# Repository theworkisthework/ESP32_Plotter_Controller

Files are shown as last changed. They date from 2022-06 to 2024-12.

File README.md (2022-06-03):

# ESP32 Plotter Controller PCB
 
Released under an MIT licence, no warranty implied or given, use at own risk etc etc.

This is a two axis stepper controller based on the ESP32 and TMC2130 stepper drivers. It is intended to be used with drawing machines and plotters.

Firmware https://github.com/theworkisthework/Grbl_Esp32 (This is a Fork of Grbl_Esp32, if its out of date, you probably only need the config file from this fork). Tested with standard and corexy kinematics and a solenoid/relay for the spindle.

Revision B (aka 'Emerald Dingo') embeds an ESP32 module on the board along with comms and USB C connector. The peripheral connectors are all JST PH2.0 connectors. Also added E-Stop connector (J18).

[Schematic]( https://github.com/theworkisthework/ESP32_Plotter_Controller/blob/main/ESP32_Plotter_Controller_Schematic_RevB1.pdf )

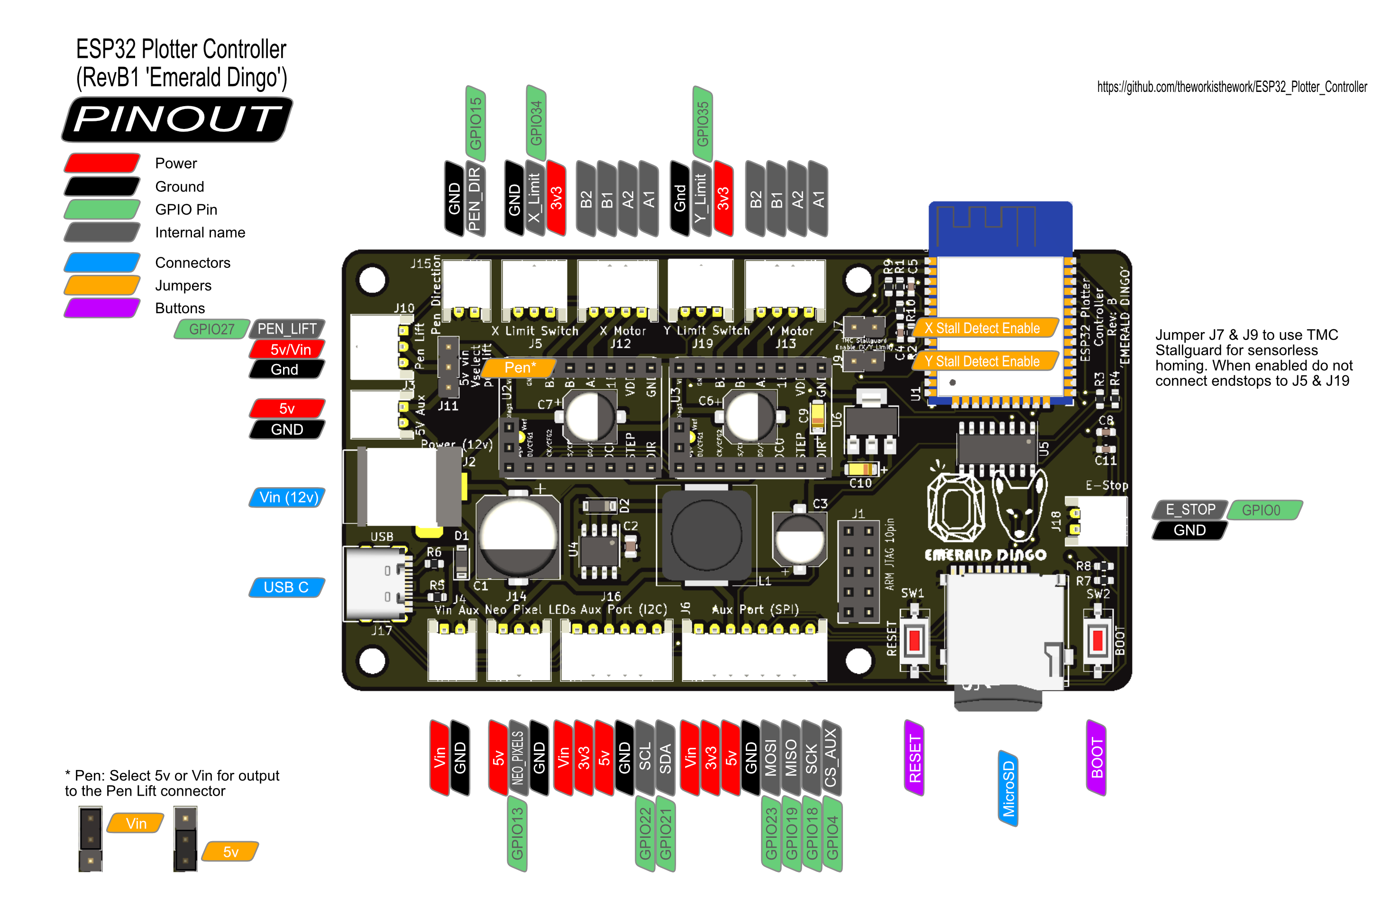
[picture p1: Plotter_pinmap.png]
Pinmap


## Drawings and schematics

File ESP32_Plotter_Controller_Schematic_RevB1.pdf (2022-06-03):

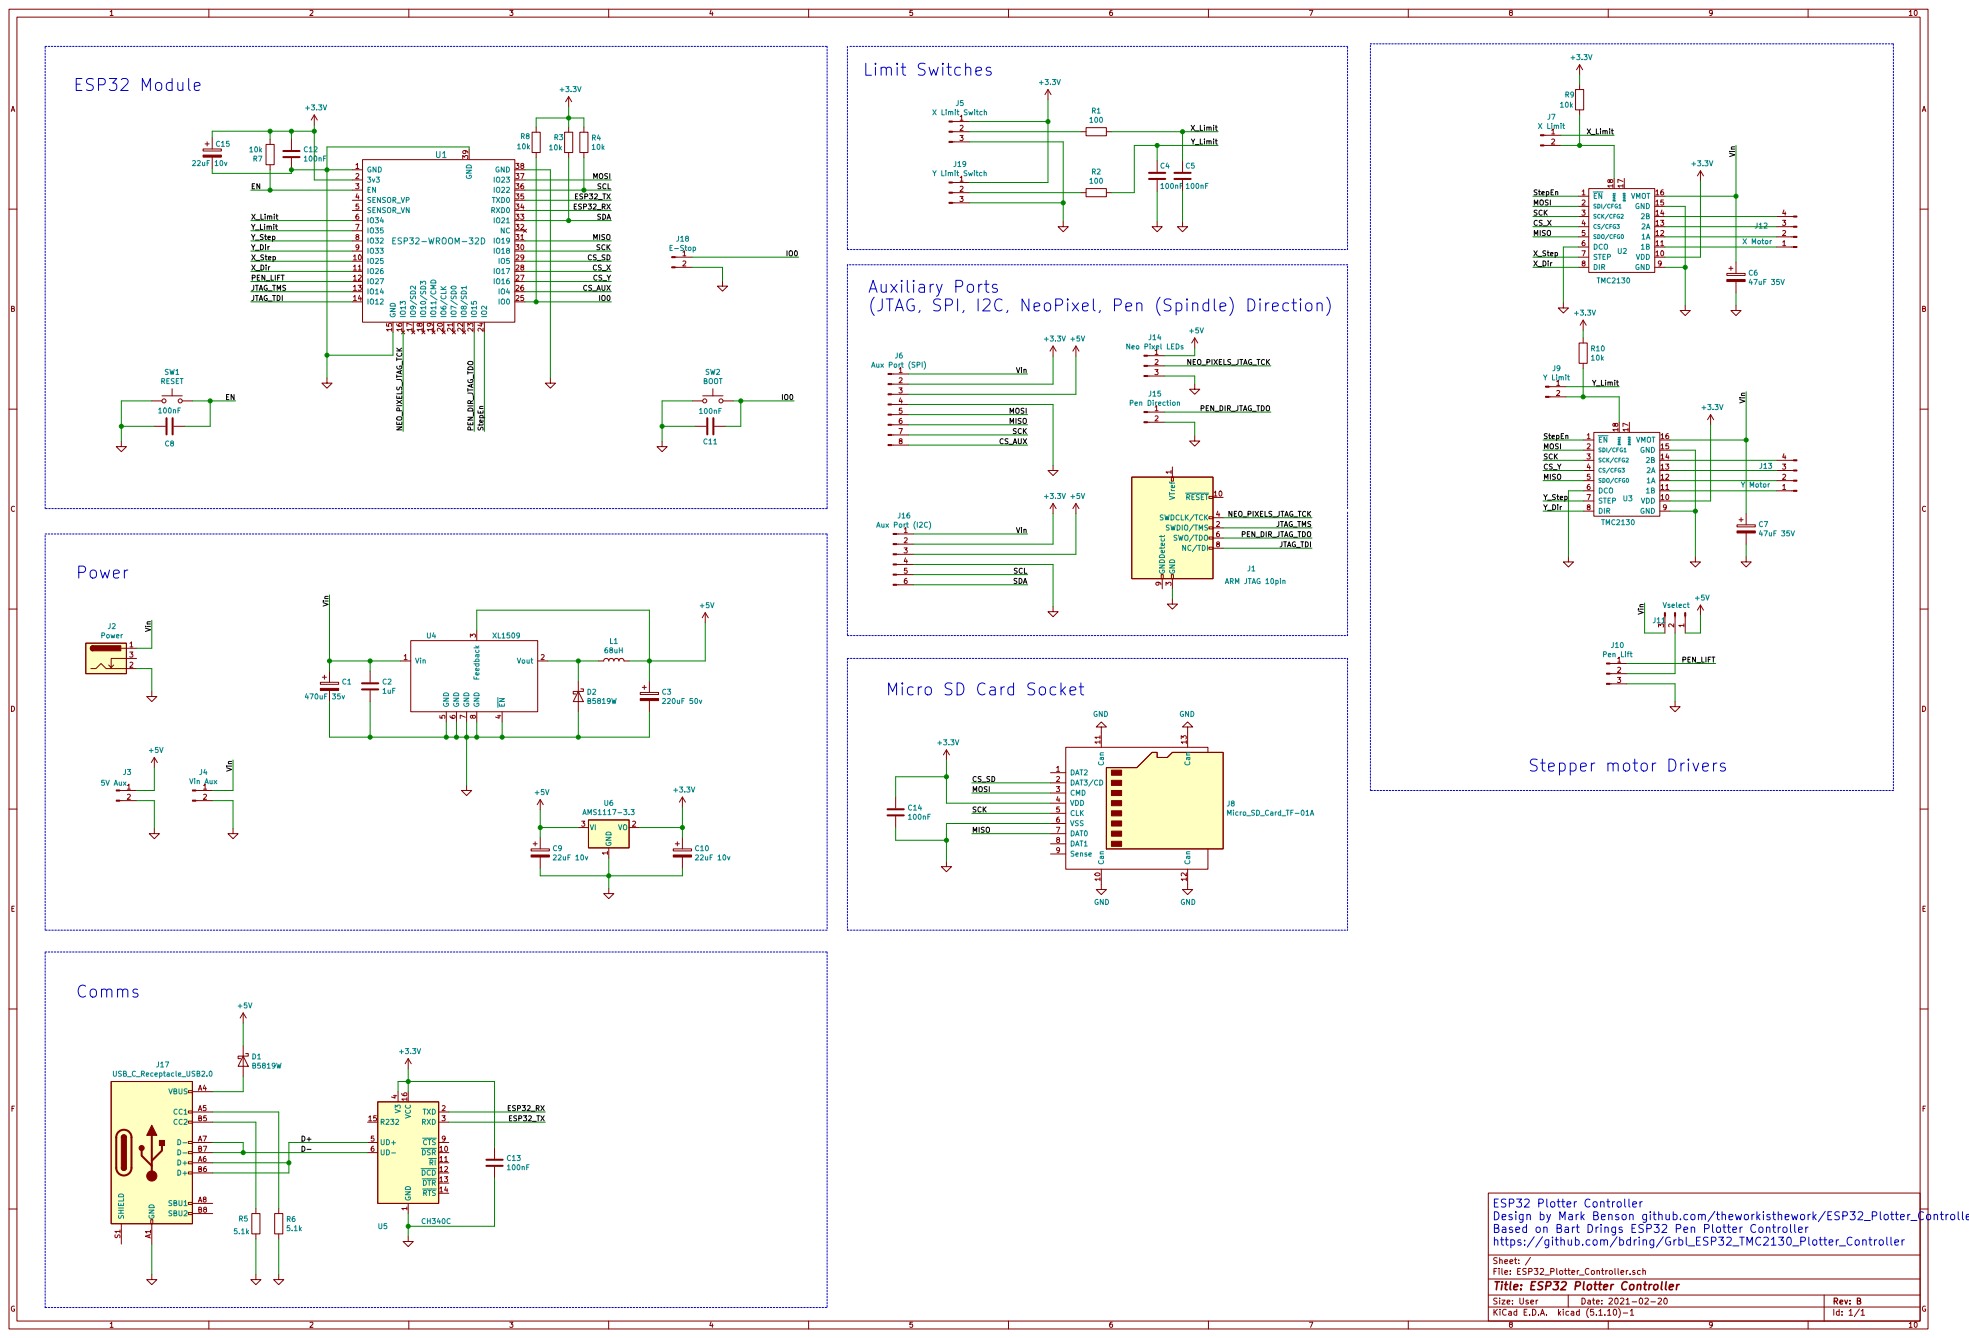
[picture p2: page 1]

Auxiliary Ports
(JTAG, SPI, I2C, NeoPixel, Pen (Spindle) Direction)

SDA MISO MOSI SCK CS_SD

3 SWDCLK/TCK 4 SWO/TDO 6 NC/TDI 8 GNDDetect 9

Micro SD Card Socket

1 DSR 10 RI 11 DCD 12 DTR 13 RTS 14 R232 15 VCC 16 TXD 2 RXD 3 V3

ESP32 Plotter Controller
Design by Mark Benson github.com/theworkisthework/ESP32_Plotter_Controller
Based on Bart Drings ESP32 Pen Plotter Controller
https://github.com/bdring/Grbl_ESP32_TMC2130_Plotter_Controller

File: ESP32_Plotter_Controller.sch Sheet: /
Id: 1/1 Title: ESP32 Plotter Controller

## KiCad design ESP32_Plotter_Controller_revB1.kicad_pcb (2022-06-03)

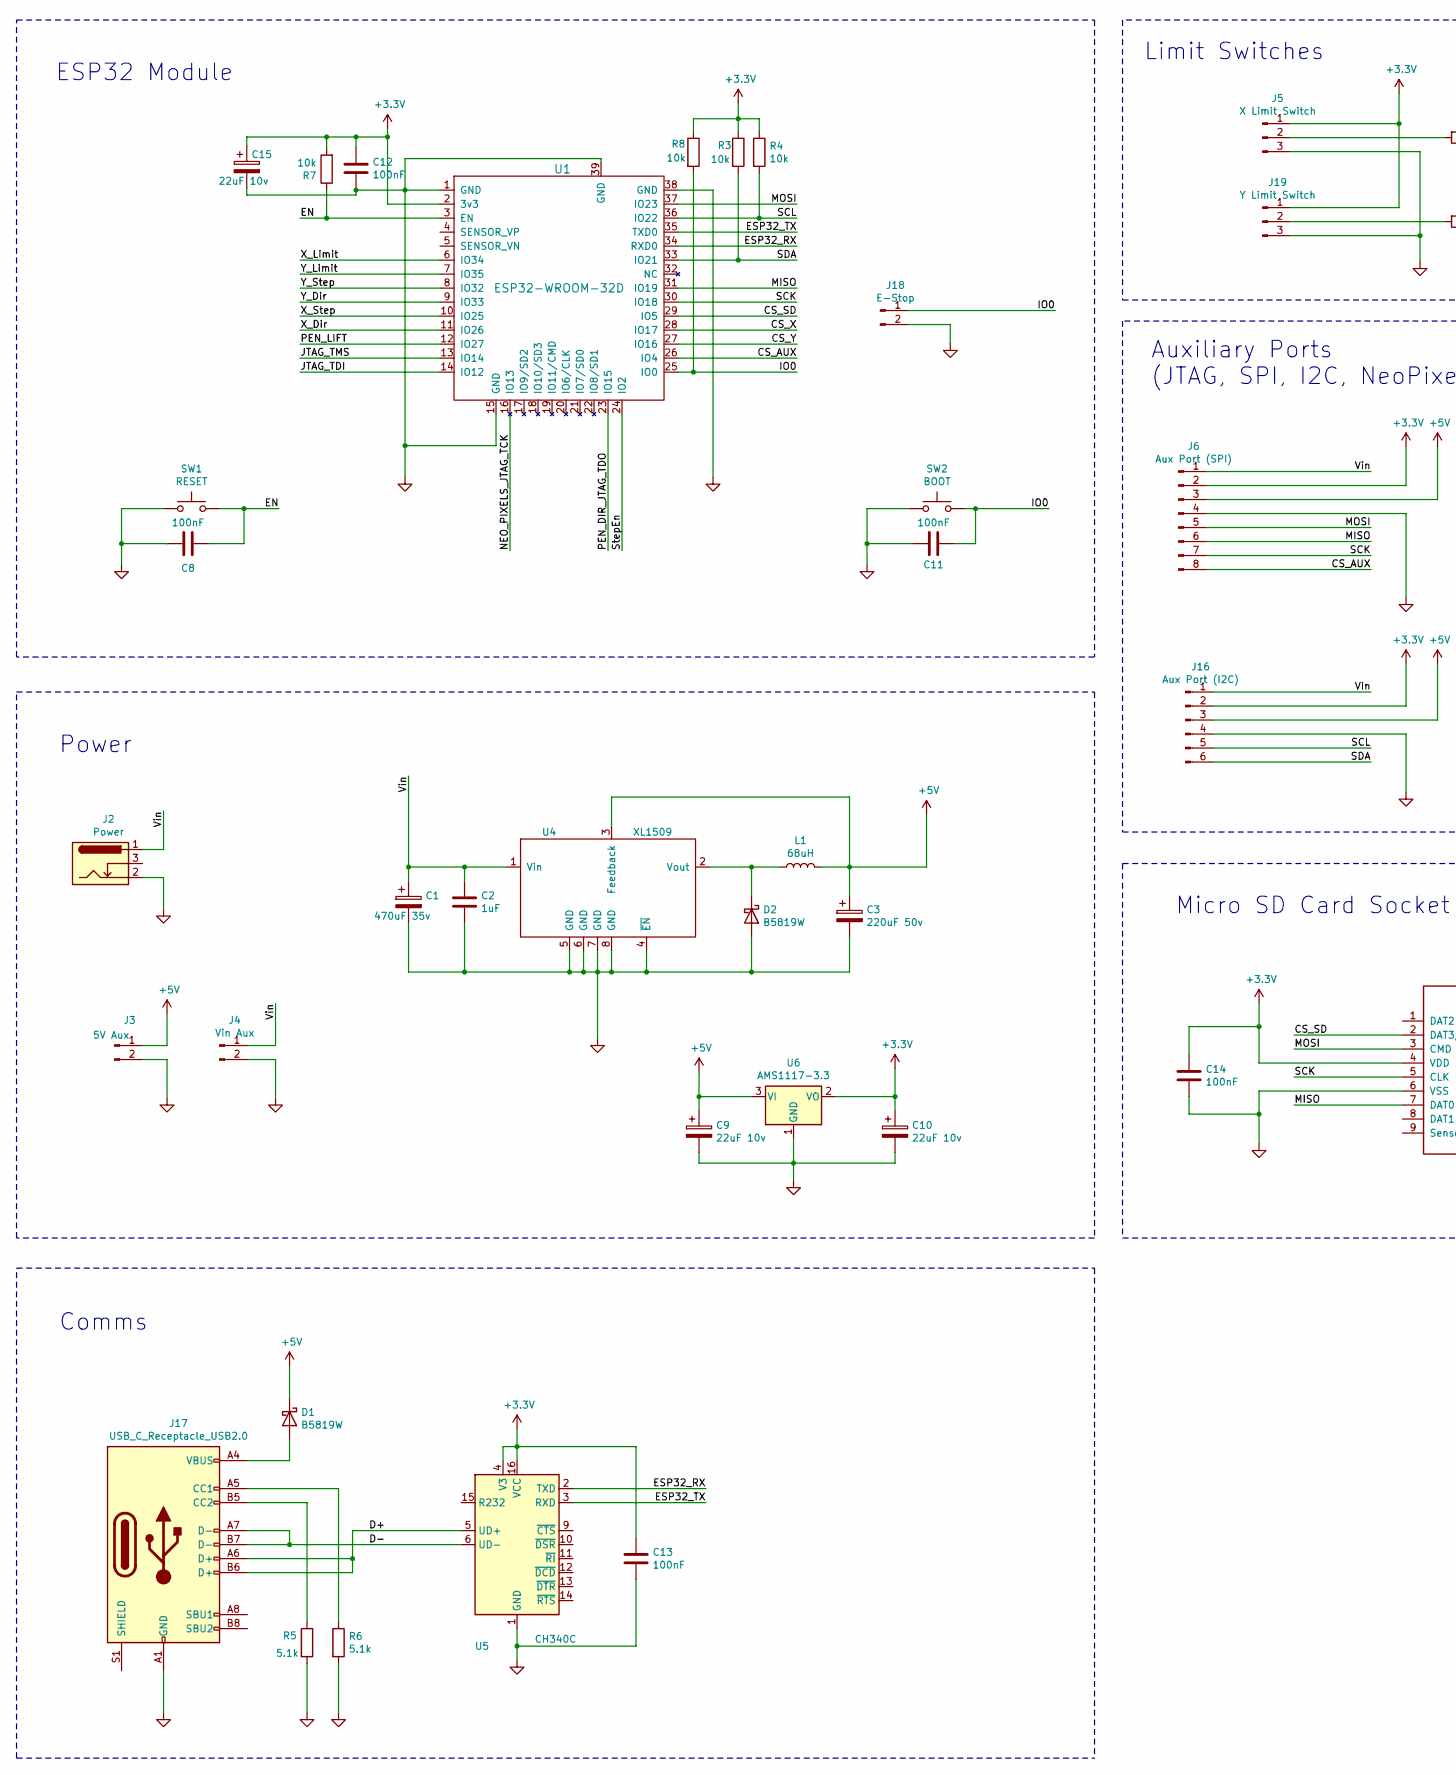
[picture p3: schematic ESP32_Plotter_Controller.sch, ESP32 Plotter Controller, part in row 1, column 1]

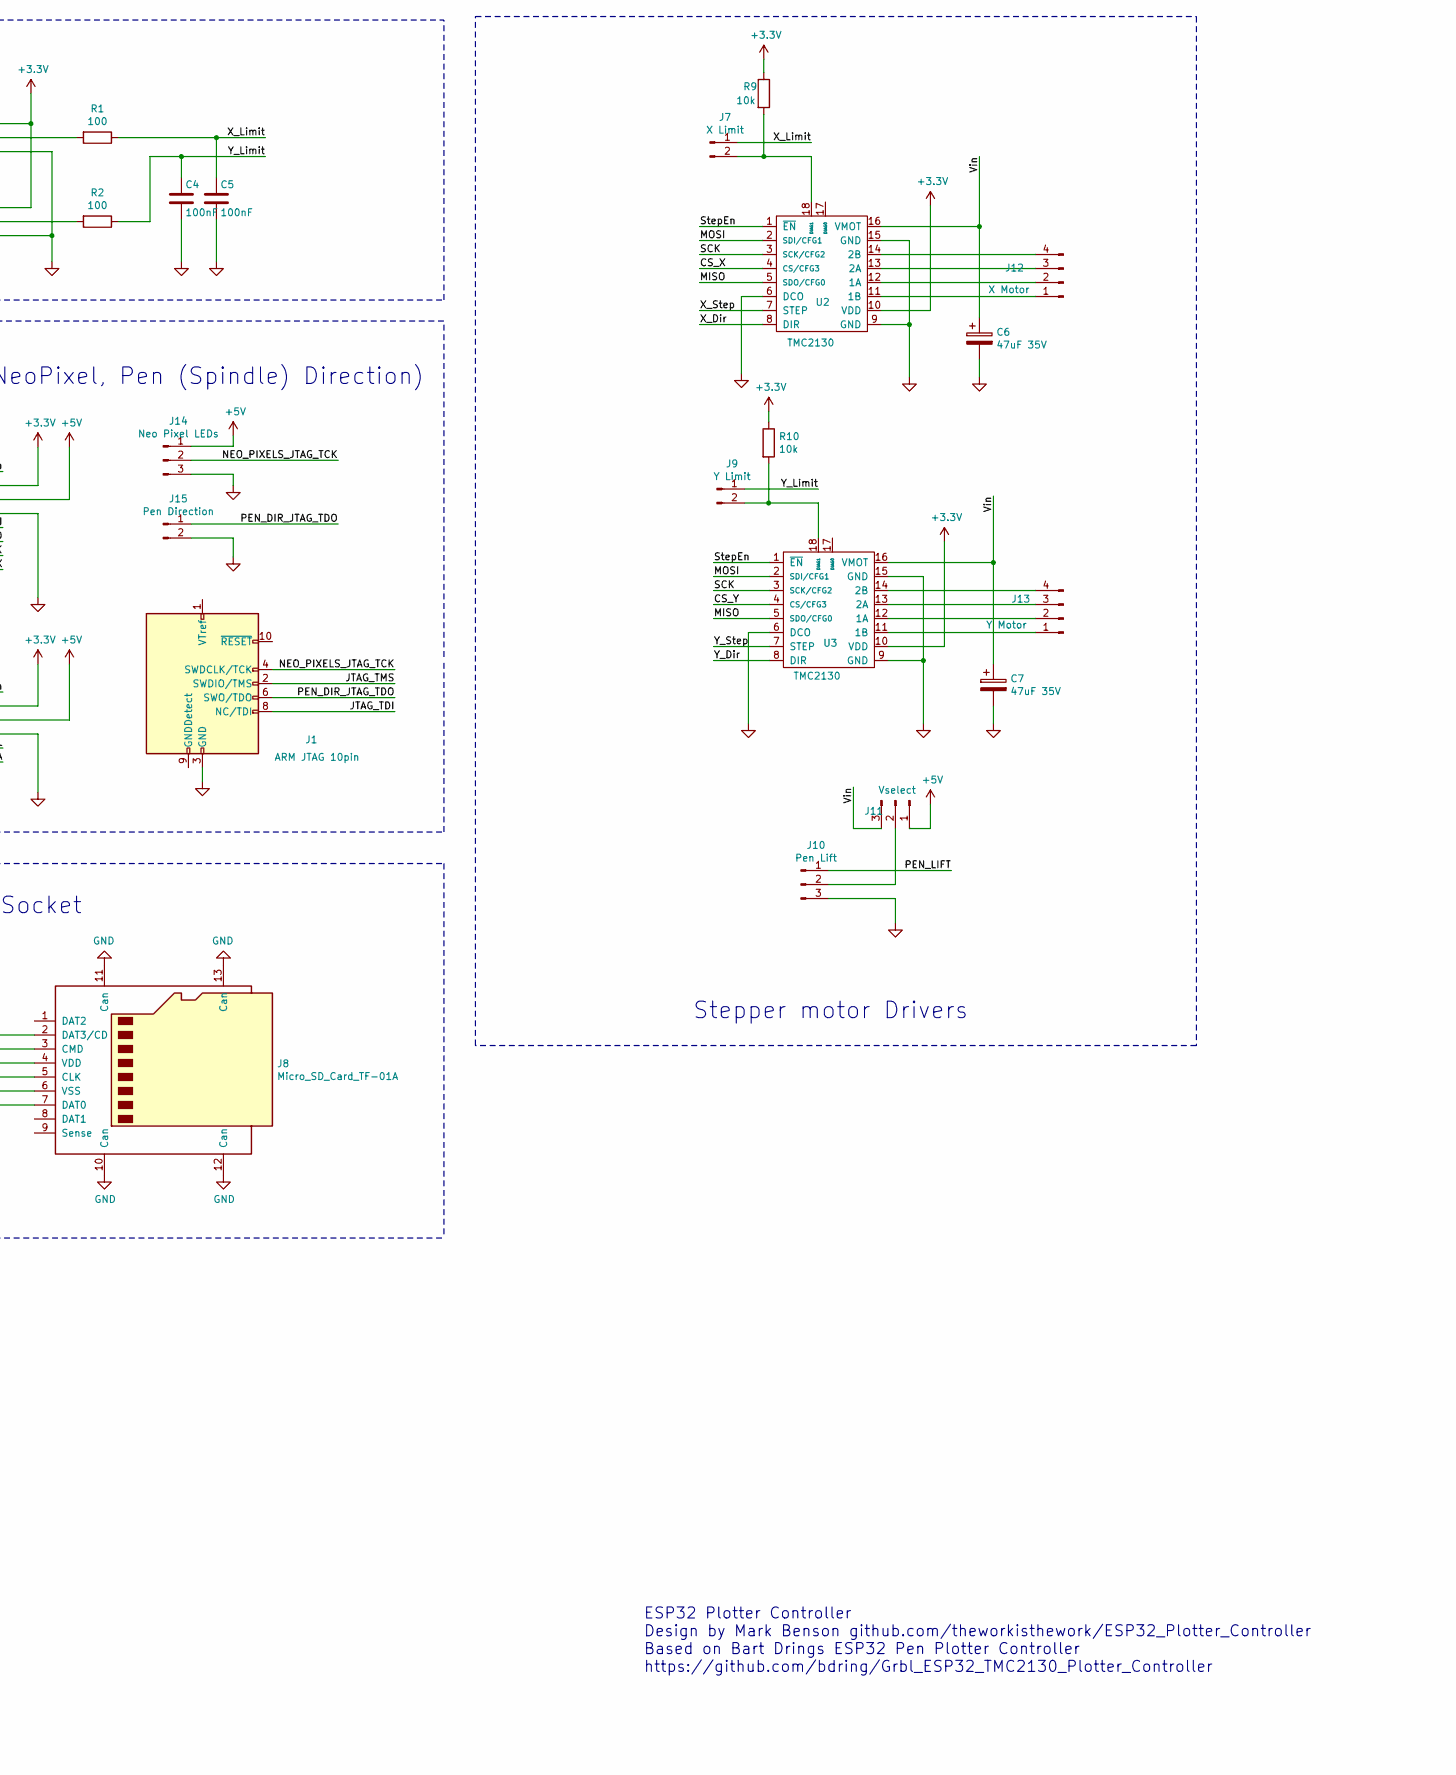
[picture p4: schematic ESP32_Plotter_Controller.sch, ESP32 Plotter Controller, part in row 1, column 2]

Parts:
C1: 470uF 35v; CP_Elec_10x10; LCSC C280412
C2: 1uF; C_0805_2012Metric; LCSC C28323
C3: 220uF 50v; CP_Elec_10x10; LCSC alt2 C242139
C4, C5, C8, C11, C12, C13, C14: 100nF; C_0603_1608Metric; LCSC C42998
C6, C7: 47uF 35V; CP_Elec_6.3x5.7; LCSC C176688
C9, C10, C15: 22uF 10v; CP_EIA-3216-18_Kemet-A; LCSC C118989
D1, D2: B5819W; D_SOD-123; LCSC C8598
J1: ARM JTAG 10pin; PinSocket_2x05_P2.54mm_Vertical; LCSC C92270
J2: Power; BarrelJack_Horizontal; LCSC C130239
J3: 5V Aux; JST_PH_S2B-PH-K_1x02_P2.00mm_Horizontal; LCSC C16965
J4: Vin Aux; JST_PH_S2B-PH-K_1x02_P2.00mm_Horizontal; LCSC C16965
J5: X Limit Switch; JST_PH_S3B-PH-K_1x03_P2.00mm_Horizontal; LCSC C10400
J6: Aux Port (SPI); JST_PH_S8B-PH-K_1x08_P2.00mm_Horizontal; LCSC C14531
J7: X Limit; PinHeader_1x02_P2.54mm_Vertical; LCSC C160332
J8: Micro_SD_Card_TF-01A; HK-TF01A; LCSC C91145
J9: Y Limit; PinHeader_1x02_P2.54mm_Vertical; LCSC C160332
J10: Pen Lift; JST_PH_S3B-PH-K_1x03_P2.00mm_Horizontal; LCSC C10400
J11: Vselect; PinHeader_1x03_P2.54mm_Vertical; LCSC C49257
J12: X Motor; JST_PH_S4B-PH-K_1x04_P2.00mm_Horizontal; LCSC C10401
J13: Y Motor; JST_PH_S4B-PH-K_1x04_P2.00mm_Horizontal; LCSC C10401
J14: Neo Pixel LEDs; JST_PH_S3B-PH-K_1x03_P2.00mm_Horizontal; LCSC C10400
J15: Pen Direction; JST_PH_S2B-PH-K_1x02_P2.00mm_Horizontal; LCSC C16965
J16: Aux Port (I2C); JST_PH_S6B-PH-K_1x06_P2.00mm_Horizontal; LCSC C5662
J17: USB_C_Receptacle_USB2.0; USB_C_Receptacle_HRO_TYPE-C-31-M-12; LCSC C165948
J18: E-Stop; JST_PH_S2B-PH-K_1x02_P2.00mm_Horizontal; LCSC C16965
J19: Y Limit Switch; JST_PH_S3B-PH-K_1x03_P2.00mm_Horizontal; LCSC C10400
L1: 68uH; L_12x12mm_H6mm; LCSC C439406
R1, R2: 100; R_0603_1608Metric; LCSC C25201
R3, R4, R7, R8, R9, R10: 10k; R_0603_1608Metric; LCSC C98220
R5, R6: 5.1k; R_0603_1608Metric; LCSC C269716
SW1: RESET; K2-1107ST; LCSC C118141
SW2: BOOT; K2-1107ST; LCSC C118141
U1: ESP32-WROOM-32D; ESP32-WROOM-32; LCSC C82899
U2, U3: TMC2130; StepstickTMCv2; LCSC C27438
U4: XL1509; SO-8_3.9x4.9mm_P1.27mm; LCSC C61063
U5: CH340C; SOIC-16_3.9x9.9mm_P1.27mm; LCSC C84681
U6: AMS1117-3.3; SOT-223-3_TabPin2; LCSC C351784

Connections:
+3V3: C10.1, C12.1, C13.1, C14.1, C15.1, J5.1, J6.2, J8.4 (VDD), J16.2, J19.1, R3.1, R4.1, R7.2, R8.1, R9.1, R10.1, U1.2 (3v3), U2.10 (VDD), U3.10 (VDD), U5.4 (V3), U5.16 (VCC), U6.2 (VO)
+5V: C3.1, C9.1, D1.1 (K), J3.1, J6.3, J11.1, J14.1, J16.3, L1.2, U4.3 (Feedback), U6.3 (VI)
/CS_AUX: J6.8, U1.26 (IO4)
/CS_SD: J8.2 (DAT3/CD), U1.29 (IO5)
/CS_X: U1.28 (IO17), U2.4 (CS/CFG3)
/CS_Y: U1.27 (IO16), U3.4 (CS/CFG3)
/D+: J17.A6 (D+), J17.B6 (D+), U5.5 (UD+)
/D-: J17.A7 (D-), J17.B7 (D-), U5.6 (UD-)
/EN: C8.2, R7.1, SW1.2, U1.3 (EN)
/ESP32_RX: U1.34 (RXD0), U5.2 (TXD)
/ESP32_TX: U1.35 (TXD0), U5.3 (RXD)
/IO0: C11.1, J18.1, R8.2, SW2.2, U1.25 (IO0)
/JTAG_TDI: J1.8 (NC/TDI), U1.14 (IO12)
/JTAG_TMS: J1.2 (SWDIO/TMS), U1.13 (IO14)
/MISO: J6.6, J8.7 (DAT0), U1.31 (IO19), U2.5 (SDO/CFG0), U3.5 (SDO/CFG0)
/MOSI: J6.5, J8.3 (CMD), U1.37 (IO23), U2.2 (SDI/CFG1), U3.2 (SDI/CFG1)
/NEO_PIXELS_JTAG_TCK: J1.4 (SWDCLK/TCK), J14.2, U1.16 (IO13)
/PEN_DIR_JTAG_TDO: J1.6 (SWO/TDO), J15.1, U1.23 (IO15)
/PEN_LIFT: J10.1, U1.12 (IO27)
/SCK: J6.7, J8.5 (CLK), U1.30 (IO18), U2.3 (SCK/CFG2), U3.3 (SCK/CFG2)
/SCL: J16.5, R4.2, U1.36 (IO22)
/SDA: J16.6, R3.2, U1.33 (IO21)
/StepEn: U1.24 (IO2), U2.1 (~EN), U3.1 (~EN)
/Vin: C1.1, C2.1, C6.1, C7.1, J2.1, J4.1, J6.1, J11.3, J16.1, U2.16 (VMOT), U3.16 (VMOT), U4.1 (Vin)
/X_Dir: U1.11 (IO26), U2.8 (DIR)
/X_Limit: C5.1, J7.1, R1.1, U1.6 (IO34)
/X_Step: U1.10 (IO25), U2.7 (STEP)
/Y_Dir: U1.9 (IO33), U3.8 (DIR)
/Y_Limit: C4.1, J9.1, R2.1, U1.7 (IO35)
/Y_Step: U1.8 (IO32), U3.7 (STEP)
GND: C1.2, C2.2, C3.2, C4.2, C5.2, C6.2, C7.2, C8.1, C9.2, C10.2, C11.2, C12.2, C13.2, C14.2, C15.2, D2.2 (A), J1.3 (GND), J1.5 (GND), J2.2, J3.2, J4.2, J5.3, J6.4, J8.6 (VSS), J8.10 (Can), J8.11 (Can), J8.12 (Can), J8.13 (Can), J10.3, J14.3, J15.2, J16.4, J17.A1 (GND), J17.A12 (GND), J17.B1 (GND), J17.B12 (GND), J18.2, J19.3, R5.2, R6.2, SW1.1, SW2.1, U1.1 (GND), U1.15 (GND), U1.38 (GND), U1.39 (GND), U2.6 (DCO), U2.9 (GND), U2.15 (GND), U3.6 (DCO), U3.9 (GND), U3.15 (GND), U4.4 (~EN), U4.5 (GND), U4.6 (GND), U4.7 (GND), U4.8 (GND), U5.1 (GND), U6.1 (GND)
unnamed: D1.2 (A), J17.A4 (VBUS), J17.A9 (VBUS), J17.B4 (VBUS), J17.B9 (VBUS)
unnamed: D2.1 (K), L1.1, U4.2 (Vout)
unnamed: J5.2, R1.2
unnamed: J7.2, R9.2, U2.18 (DIAG1)
unnamed: J9.2, R10.2, U3.18 (DIAG1)
unnamed: J10.2, J11.2
unnamed: J12.1, U2.11 (1B)
unnamed: J12.2, U2.12 (1A)
unnamed: J12.3, U2.13 (2A)
unnamed: J12.4, U2.14 (2B)
unnamed: J13.1, U3.11 (1B)
unnamed: J13.2, U3.12 (1A)
unnamed: J13.3, U3.13 (2A)
unnamed: J13.4, U3.14 (2B)
unnamed: J17.A5 (CC1), R6.1
unnamed: J17.B5 (CC2), R5.1
unnamed: J19.2, R2.2

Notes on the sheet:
Micro SD Card Socket
Limit Switches
Stepper motor Drivers
ESP32 Module
Power
ESP32 Plotter Controller Design by Mark Benson github.com/theworkisthework/ESP32_Plotter_Controller Based on Bart Drings ESP32 Pen Plotter Controller https://github.com/bdring/Grbl_ESP32_TMC2130_Plotter_Controller
Auxiliary Ports (JTAG, SPI, I2C, NeoPixel, Pen (Spindle) Direction)
Comms

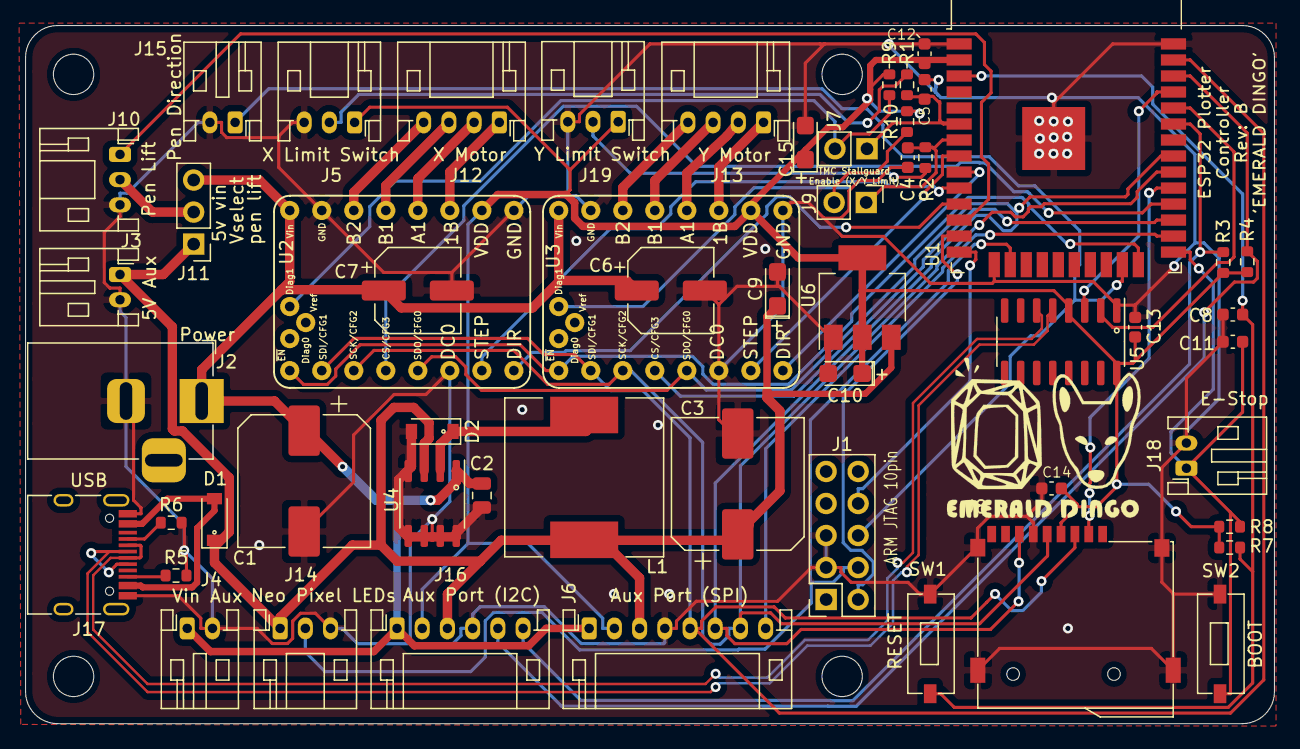
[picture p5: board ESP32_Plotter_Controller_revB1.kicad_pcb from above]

Board: 2 copper layers, 99.1 x 55.4 mm, 61 parts (1 on the bottom side), 48 nets.

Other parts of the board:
G1: LOGO; emerald_dingo_400
G2: LOGO; emerald_dingo_150
H1, H2, H3, H4: MountingHole_3.2mm_M3

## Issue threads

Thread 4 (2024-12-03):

Pin map Y Limit Switch labels incorrect

MarkJB, 2024-12-03:
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

Swap PWR & GND on J19

Closed 2024-12-07.

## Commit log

2022-06-03 Update repo links
    [ESP32_Plotter_Controller.sch, ESP32_Plotter_Controller_revB1.kicad_pcb]
2022-06-03 Update gerber files
    [ESP32_Plotter_Controller_revB1-B_Cu.gbl, ESP32_Plotter_Controller_revB1-B_Mask.gbs, ESP32_Plotter_Controller_revB1-B_Paste.gbp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]
2022-06-12 Fix solenoid pin order on pinmap
    GND and En pins were swapped on diagram. Fixed in this version
2024-12-06 Fix J19 pins swapped on pin map
2025-06-03 Add TMC2130-LA on-board drivers
2025-06-03 Might as well add a z motor stepper driver at this stage
2025-06-03 Assign JTAG pins to Z stepper driver. Remove JTAG, Pen Direction and Neo Pixel ports
